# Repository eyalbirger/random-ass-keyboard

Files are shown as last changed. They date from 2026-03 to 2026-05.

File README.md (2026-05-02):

# random ass keyboard
this is my first entery into the stm32 world... im building a stm32 numpad +4keys + knob + under glow hot swap build. i will be using zmk and jlcPCBA service.

to use this you will need to program it via qmk, and solder the pcb yourself. you will also need hardware to assemble it.

BOM:

| quantity | name | value/lcsc |
|:---:|:----:|:---|
| 21 | hot swap sockets | . |
| 1 | ec11 | . |
| 1 | push button | TL3342 |
| 1 | esd | USBLC6-2SC6 |
| 1 | fuse | Fuse_0603 |
| 5 | capacitor 0402 | 100nF |
| 3 | capacitor 0402 | 1uF |
| 2 | capacitor 0402 | 4.7uF |
| 1 | polarized capacitor | 100uF, 10v |
| 2 | resistor 0402 | 5.1k |
| 1 | resistor 0402 | 10k |
| 1 | resistor 0805 | 330R |
| 22 | diode sod | 123 |
| 12 | led | ws2812b |
| 1 | stm32 | stm32f072cbt6 |
| 1 | voltage regulator | XC6206 |
| 1 | usb c | USB_C_HRO_TYPE-C-31-M-12 |  
---
  
this should cost about 150$
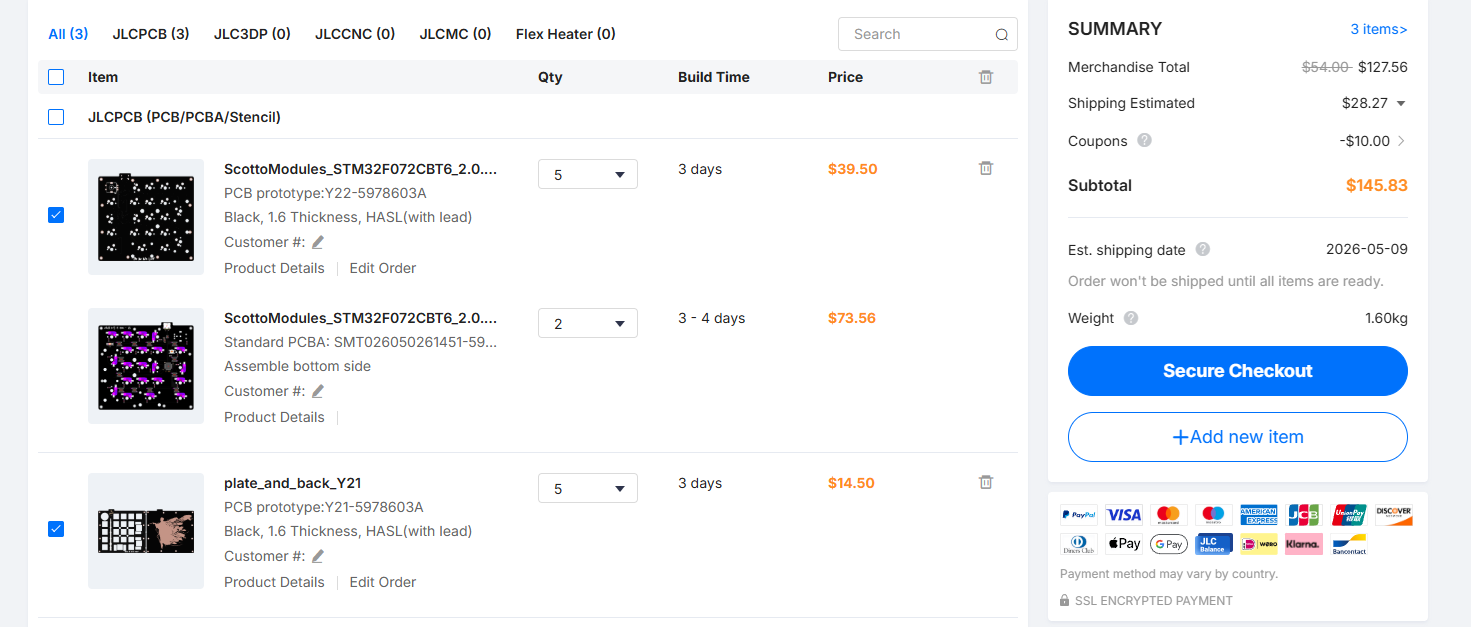
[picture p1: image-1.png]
  
this is the board.
you should have the pcb seperated from the plate and back.
you should assemble them with m2 screws and then put the switches in.
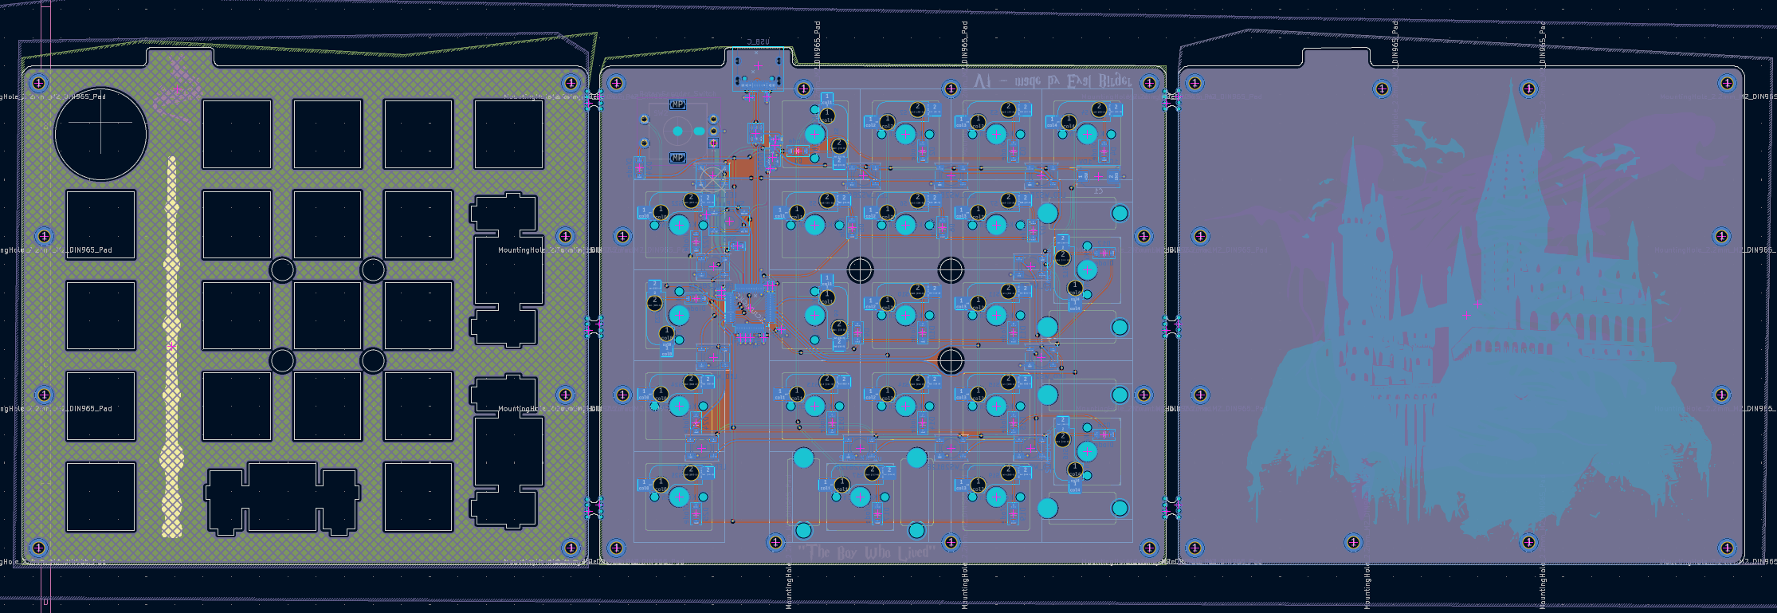
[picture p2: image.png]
  
qmk firmware will be coming shortly

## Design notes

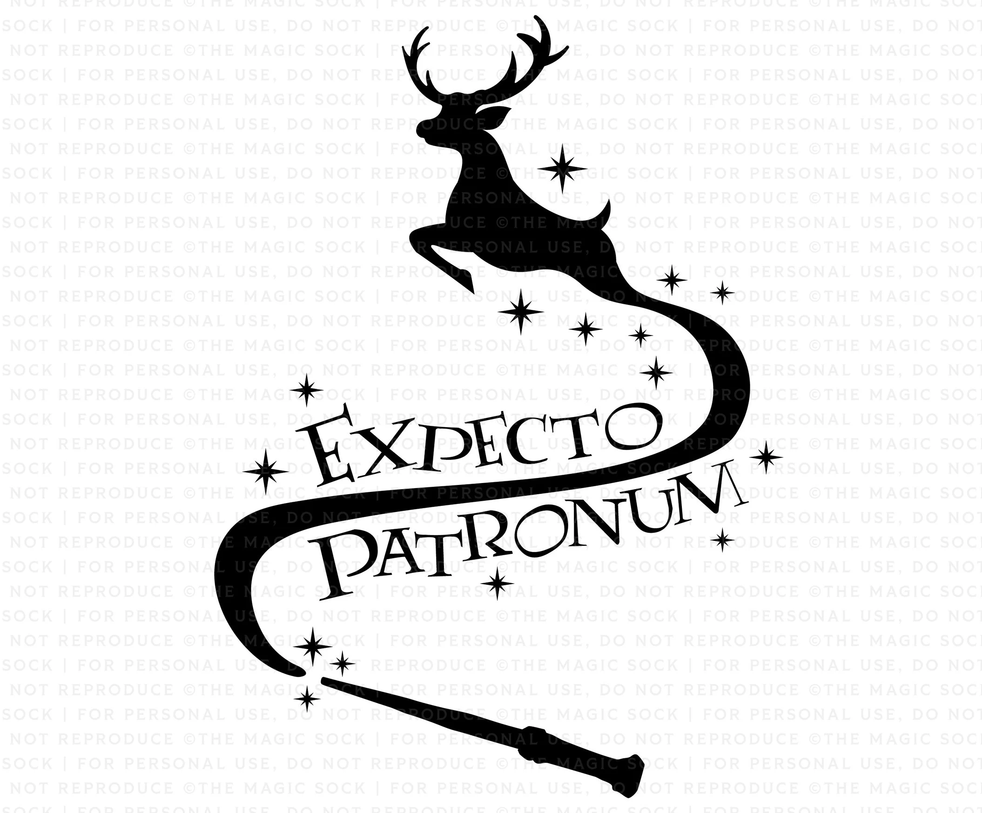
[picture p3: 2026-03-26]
pngs/patronus wand.png

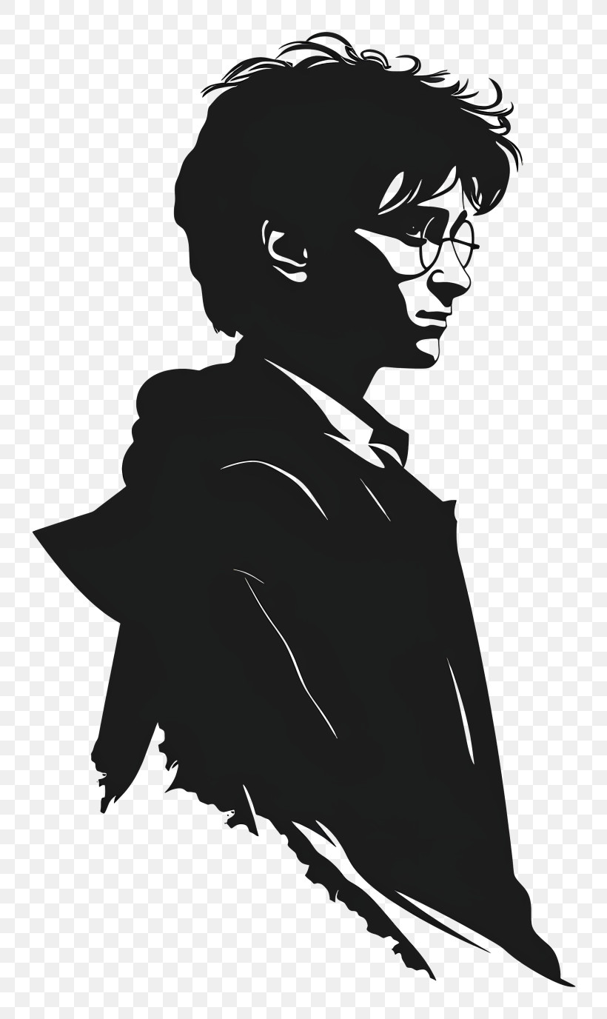
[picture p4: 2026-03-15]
pngs/harry-potter-silhouette-black-silhouette-with-glasses-88E9S3ip.jpg

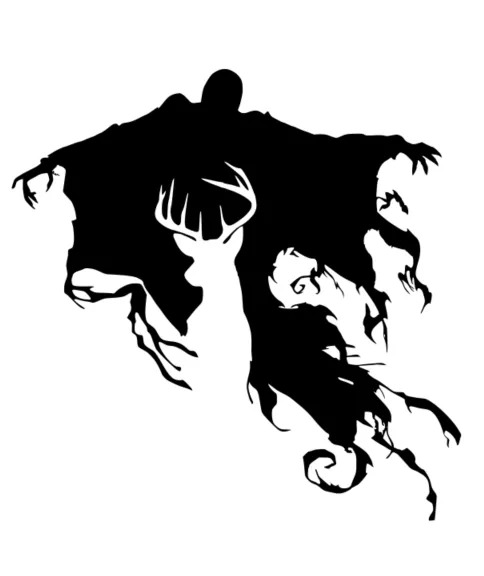
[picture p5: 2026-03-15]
pngs/1-76586c70.jpg

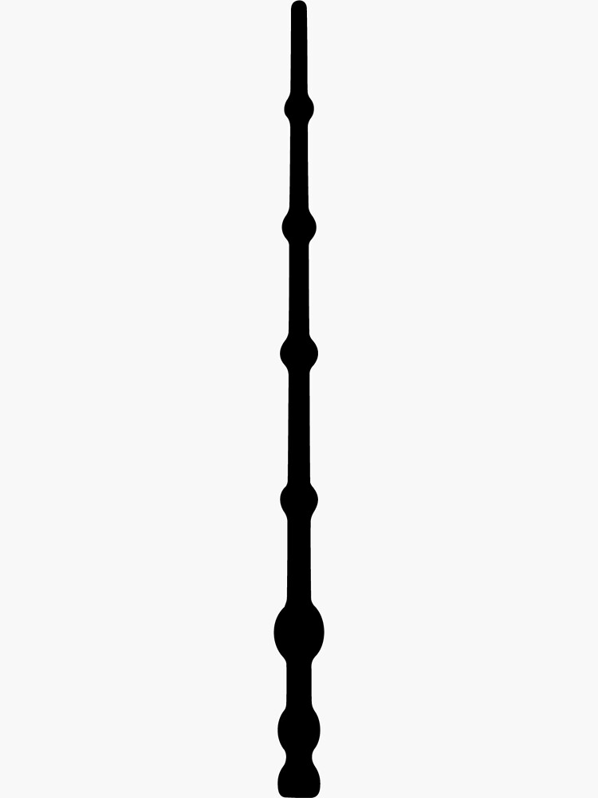
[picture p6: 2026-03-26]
pngs/elder wand.jpg

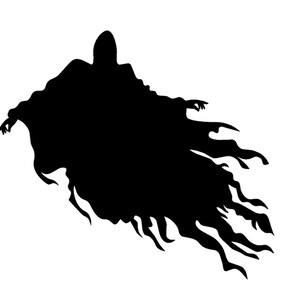
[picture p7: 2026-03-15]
pngs/il_300x300.7690259592_6foi.jpg

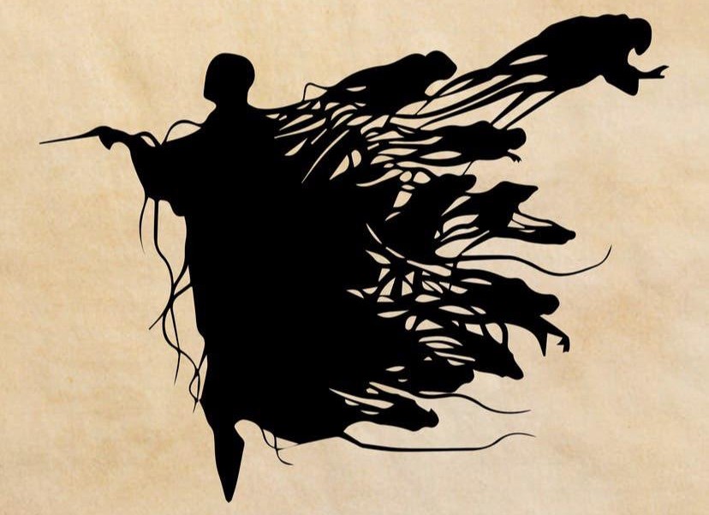
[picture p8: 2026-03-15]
pngs/voldemort-silhouettes-from-etsy-v0-3fsgxhvfzv461.jpg

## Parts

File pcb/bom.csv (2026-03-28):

Designator | Footprint | Quantity | Value | LCSC Part #
C1 | CP_EIA-7343-31_Kemet-D_HandSolder | 1 | 100µF 10V | C16133
C10, C11, C13, C16, C7 | Capacitor_0402 | 5 | 100nF | C307331
C12, C17 | Capacitor_0402 | 2 | 4.7uF | C23733
C14 | Capacitor_0402 | 1 | 10nF | C15195
C15, C8, C9 | Capacitor_0402 | 3 | 1uF | C52923
D1, D10, D11, D12, D13, D14, D15, D16, D17, D19, D2, D22, D23, D24, D25, D3, D34, D4, D5, D6, D7, D9 | Diode_SOD-123 | 22 | Diode | C2128
D18, D20, D21, D26, D27, D28, D29, D30, D31, D32, D33, D8 | LED_WS2812B | 12 | LED_WS2812B | C292004
F1 | Fuse_0603 | 1 | 500mA | C210357
J1 | USB_C_HRO_TYPE-C-31-M-12 | 1 | USB_C | C165948
R1 | Resistor_0402 | 1 | 10k | C25744
R2, R3 | Resistor_0402 | 2 | 5.1k | C25905
R4 | Resistor_0805 | 1 | 330R | C23138
S1 | SW_MX_HS_CPG151101S11_1u | 1 | Keyswitch
S10, S11, S13, S14, S15, S19, S2, S22, S23, S24, S25, S3, S4, S5, S6, S7, S9 | SW_MX_HS_CPG151101S11_1u | 17 | Keyswitch | CPG151101S11-16
S12, S16, S17 | SW_MX_HS_CPG151101S11_1.5u | 3 | Keyswitch | CPG151101S11-16
SW1 | Button_TL3342 | 1 | SW_Push | C115351
SW2 | RotaryEncoder_Alps_EC11E-Switch_Vertical_H20mm_MountingHoles | 1 | RotaryEncoder_Switch
U1 | Package_LQFP-48_7x7mm_P0.5 | 1 | STM32F072CBT6 | C81720
U3 | Voltage_SOT-23 | 1 | XC6206 | C5446
U4 | ESD_SOT-23-6 | 1 | USBLC6-2SC6 | C2827654

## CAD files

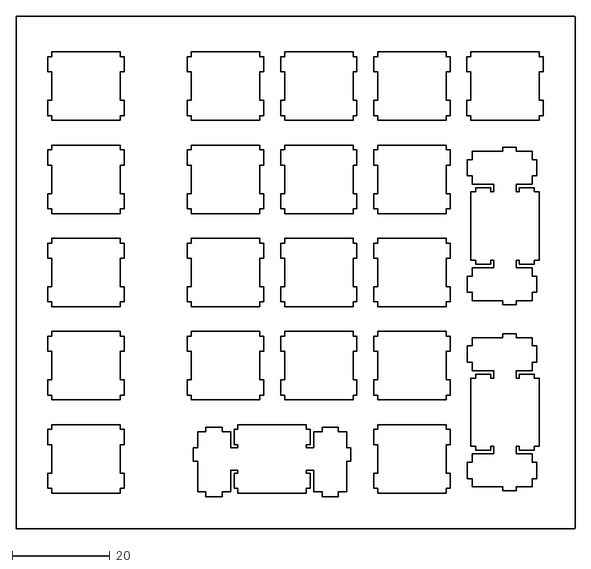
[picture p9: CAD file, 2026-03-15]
pcb/dxf_for_keyboard.dxf
114.3 x 104.8

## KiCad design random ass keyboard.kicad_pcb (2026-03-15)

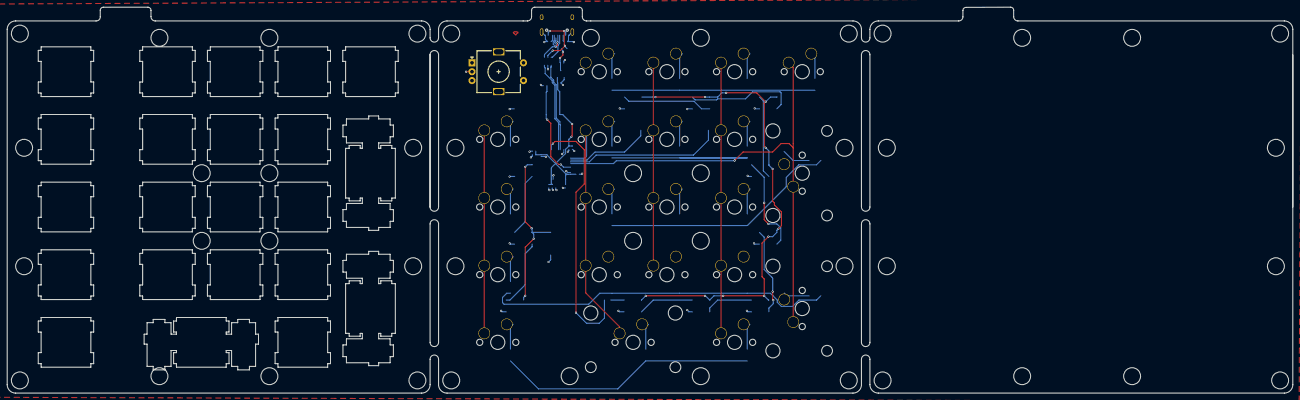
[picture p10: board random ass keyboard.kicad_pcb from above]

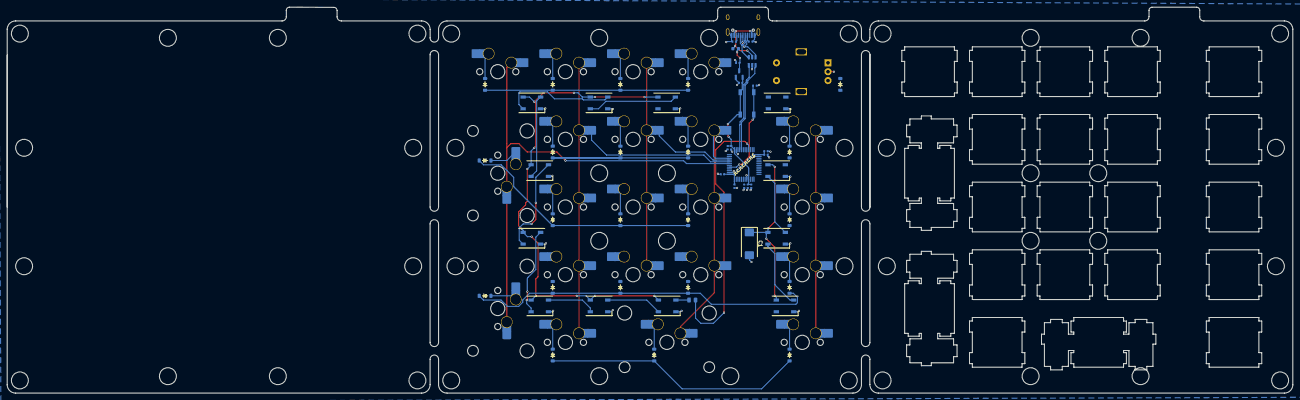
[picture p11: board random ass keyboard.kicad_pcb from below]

Board: 4 copper layers, 361.9 x 108.6 mm, 78 parts (77 on the bottom side), 59 nets.

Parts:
C1: C_Polarized; CP_EIA-7343-31_Kemet-D_HandSolder
C7, C10, C11, C13, C16: 100nF; Capacitor_0402
C8, C9, C15: 1uF; Capacitor_0402
C12, C17: 4.7uF; Capacitor_0402
C14: 10nF; Capacitor_0402
D1, D2, D3, D4, D5, D6, D7, D9, D10, D11, D12, D13, D14, D15, D16, D17, D19, D22, D23, D24, D25, D45: Diode; Diode_SOD-123
D8, D18, D20, D21, D26, D27, D28, D29, D30, D31, D32, D33: LED_WS2812B
F1: 500mA; Fuse_0603
J1: USB_C; USB_C_HRO_TYPE-C-31-M-12
MT1: PEC11R-4215F-S0024; RotaryEncoder_Alps_EC11E-Switch_Vertical_H20mm
R1: 10k; Resistor_0402
R2, R3: 5.1k; Resistor_0402
R4: Resistor; Resistor_0805
S1, S2, S3, S4, S5, S6, S7, S9, S10, S11, S13, S14, S15, S19, S22, S23, S24, S25: Keyswitch; SW_MX_HS_CPG151101S11_1u
S12, S16, S17: Keyswitch; SW_MX_HS_CPG151101S11_1.5u
SW1: SW_Push; Button_TL3342
U1: STM32F072CBT6; Package_LQFP-48_7x7mm_P0.5
U3: XC6206; Voltage_SOT-23
U4: USBLC6-2SC6; ESD_SOT-23-6

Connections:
+3.3V: C9.1, C10.2, C11.2, C12.2, C13.2, C14.2, C15.2, C16.2, C17.2, SW1.1, U1.1 (VBAT), U1.9 (VDDA), U1.24 (VDD), U1.36 (VDDIO2), U1.48 (VDD), U3.2 (VO)
+5V: C1.1, C8.1, D8.1 (VDD), D18.1 (VDD), D20.1 (VDD), D21.1 (VDD), D26.1 (VDD), D27.1 (VDD), D28.1 (VDD), D29.1 (VDD), D30.1 (VDD), D31.1 (VDD), D32.1 (VDD), D33.1 (VDD), F1.2, U3.3 (VI)
/B0: MT1.A, U1.18 (PB0)
/B1: MT1.B, U1.19 (PB1)
/B15: R4.1, U1.28 (PB15)
/BOOT0: R1.2, SW1.2, U1.44 (BOOT0)
/MCU_D+: U1.33 (PA12), U4.1 (I/O1)
/MCU_D-: U1.32 (PA11), U4.3 (I/O2)
/NRST: C7.1, U1.7 (NRST)
/USB_D+: J1.A6 (D+), J1.B6 (D+), U4.6 (I/O1)
/USB_D-: J1.A7 (D-), J1.B7 (D-), U4.4 (I/O2)
/col0: S22.1, S23.1, S24.1, S25.1, U1.20 (PB2)
/col1: S1.1, S5.1, S9.1, S13.1, S17.1, U1.39 (PB3)
/col2: S2.1, S6.1, S10.1, S14.1, U1.40 (PB4)
/col3: S3.1, S7.1, S11.1, S15.1, S19.1, U1.41 (PB5)
/col4: S4.1, S12.1, S16.1, U1.42 (PB6)
/row0: D17.1 (K), D19.1 (K), D25.1 (K), U1.43 (PB7)
/row1: D13.1 (K), D14.1 (K), D15.1 (K), D16.1 (K), D24.1 (K), U1.45 (PB8)
/row2: D9.1 (K), D10.1 (K), D11.1 (K), D12.1 (K), D23.1 (K), U1.46 (PB9)
/row3: D5.1 (K), D6.1 (K), D7.1 (K), D22.1 (K), U1.21 (PB10)
/row4: D1.1 (K), D2.1 (K), D3.1 (K), D4.1 (K), D45.1 (K), U1.22 (PB11)
GND: C1.2, C7.2, C8.2, C9.2, C10.1, C11.1, C12.1, C13.1, C14.1, C15.1, C16.1, C17.1, D8.3 (VSS), D18.3 (VSS), D20.3 (VSS), D21.3 (VSS), D26.3 (VSS), D27.3 (VSS), D28.3 (VSS), D29.3 (VSS), D30.3 (VSS), D31.3 (VSS), D32.3 (VSS), D33.3 (VSS), J1.A1 (GND), J1.A12 (GND), J1.B1 (GND), J1.B12 (GND), J1.S1 (SHIELD), R1.1, R2.2, R3.2, U1.8 (VSSA), U1.23 (VSS), U1.35 (VSS), U1.47 (VSS), U3.1 (GND), U4.2 (GND)
unnamed: D1.2 (A), S1.2
unnamed: D2.2 (A), S2.2
unnamed: D3.2 (A), S3.2
unnamed: D4.2 (A), S4.2
unnamed: D5.2 (A), S5.2
unnamed: D6.2 (A), S6.2
unnamed: D7.2 (A), S7.2
unnamed: D8.4 (DIN), R4.2
unnamed: D9.2 (A), S9.2
unnamed: D10.2 (A), S10.2
unnamed: D11.2 (A), S11.2
unnamed: D12.2 (A), S12.2
unnamed: D13.2 (A), S13.2
unnamed: D14.2 (A), S14.2
unnamed: D15.2 (A), S15.2
unnamed: D16.2 (A), S16.2
unnamed: D17.2 (A), S17.2
unnamed: D8.2 (DOUT), D18.4 (DIN)
unnamed: D18.2 (DOUT), D20.4 (DIN)
unnamed: D19.2 (A), S19.2
unnamed: D20.2 (DOUT), D21.4 (DIN)
unnamed: D21.2 (DOUT), D26.4 (DIN)
unnamed: D22.2 (A), S22.2
unnamed: D23.2 (A), S23.2
unnamed: D24.2 (A), S24.2
unnamed: D25.2 (A), S25.2
unnamed: D26.2 (DOUT), D27.4 (DIN)
unnamed: D27.2 (DOUT), D33.4 (DIN)
unnamed: D28.4 (DIN), D29.2 (DOUT)
unnamed: D29.4 (DIN), D30.2 (DOUT)
unnamed: D30.4 (DIN), D31.2 (DOUT)
unnamed: D31.4 (DIN), D32.2 (DOUT)
unnamed: D32.4 (DIN), D33.2 (DOUT)
unnamed: J1.A5 (CC1), R2.1
unnamed: J1.B5 (CC2), R3.1
unnamed: MT1.S1 (SHIELD), MT1.S2 (SHIELD)
VBUS: F1.1, J1.A4 (VBUS), J1.A9 (VBUS), J1.B4 (VBUS), J1.B9 (VBUS), U4.5 (VBUS)

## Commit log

2026-03-17 i... actually finished this shit.
    [random ass keyboard.kicad_sch]
2026-03-17 fab files but also i need to add silk screen
    [bom.csv, designators.csv, positions.csv]
2026-03-18 bom and fab
    [random ass keyboard.csv]
2026-03-18 other things
    [random ass keyboard.kicad_sch]
2026-03-25 fixed screw hole and knob hole
2026-03-26 bom, readme, garber and pcb art
    [bom.csv, designators.csv, random ass keyboard.csv]
2026-03-26 updated that one diode
    [random ass keyboard.kicad_sch]
2026-03-26 upgraded to kicad ten and it gave me so much problemssss
2026-03-27 finalll shit
    [designators.csv, positions.csv]
2026-03-28 changed the plate
    [bom.csv]
2026-03-28 change the plate
2026-05-02 pcb and organized
    [bom.csv, designators.csv, dxf_for_keyboard.dxf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]
